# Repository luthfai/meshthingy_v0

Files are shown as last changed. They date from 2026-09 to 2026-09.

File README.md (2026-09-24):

# meshthingy v0

> An off-grid LoRa mesh communicator — a pocket-sized ESP32-S3 node that sends
> text and GPS position over kilometres of open ground, with no cell tower, no
> SIM, no subscription, and no internet.

<sub>KiCad 10 · 2-layer · 71 × 46 mm · ESP32-S3 + SX1262-class LoRa · USB-C · Li-Ion</sub>

<p align="center">
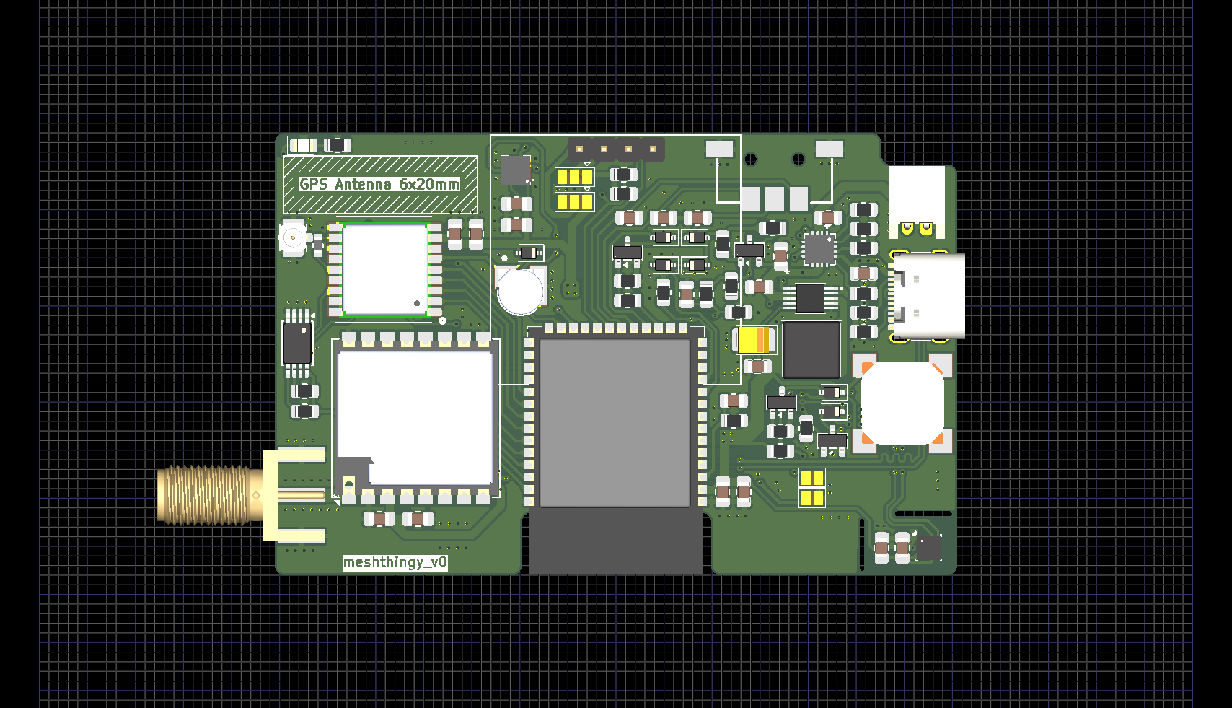
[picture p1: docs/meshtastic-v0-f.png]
meshthingy v0 board, front view
  
</p>

---

## What this board is for

Phones stop working the moment you leave coverage. **meshthingy** doesn't need
coverage — it *is* the network.

Each board is one node in a self-healing [Meshtastic](https://meshtastic.org)
mesh. Nodes talk directly to each other over licence-free LoRa radio, and every
node automatically relays traffic for its neighbours. Two units give you a
private long-range walkie-talkie for text; a handful scattered across a valley,
a campsite, a ridgeline, or a city block give everyone in that area a shared
messaging network that keeps working when nothing else does.

Because LoRa trades bandwidth for range and power, a node runs for **days** on a
small Li-Ion cell and reaches **several kilometres** line-of-sight — far past
Wi-Fi or Bluetooth, and without the power budget a cellular radio demands.

Typical uses: hiking and backcountry trips, sailing, off-road convoys, festival
and event crews, neighbourhood emergency preparedness, and as a low-cost
long-range telemetry link for remote sensors.

The onboard GPS, environmental and motion sensors mean a node is useful even
with nobody holding it — drop one on a hilltop as a solar-powered repeater and
it becomes a weather station that also extends everyone's range.

## Features

- **ESP32-S3-WROOM-1** — dual-core MCU with Wi-Fi and Bluetooth LE for phone pairing
- **HT-RA62 LoRa module** — long-range sub-GHz radio, U.FL *and* SMA edge-mount antenna options
- **ATGM336H GNSS** — position reporting, with a rechargeable backup cell for warm starts
- **0.96" OLED** — read messages without a phone
- **BME280** — temperature, humidity, barometric pressure
- **LIS3DSH accelerometer** — wake-on-motion and orientation, with interrupt to the MCU
- **USB-C charging** — BQ24072 Li-Ion charger with power-path, so it runs while charging
- **JST-PH battery connector** — standard single-cell Li-Ion / LiPo
- **Vibration motor driver** — SI2302 low-side switch with flyback diode, for silent alerts in a pocket
- **Buzzer, status LED, and a side lever switch** for headless operation
- **Test points** on every bus for bring-up and debugging

## System architecture

```mermaid
flowchart TB
    subgraph RF["📡 Radio"]
        LORA["<b>U4 · HT-RA62</b><br/>LoRa transceiver"]
        UFL["J3 · U.FL"]
        SMA["J4 · SMA<br/>edge mount"]
        LORA --- UFL
        LORA --- SMA
    end

    subgraph CORE["🧠 Core"]
        MCU["<b>U7 · ESP32-S3-WROOM-1</b><br/>Wi-Fi · BLE · dual core"]
    end

    subgraph NAV["🛰️ Navigation"]
        GPS["<b>U2 · ATGM336H</b><br/>GNSS receiver"]
        EEP["U8 · AT24C32<br/>almanac EEPROM"]
        BAT2["C13 · XH414H<br/>backup cell"]
        GPS -->|"private I²C"| EEP
        BAT2 -.->|"keeps time"| GPS
    end

    subgraph IO["🔌 I²C peripherals"]
        OLED["U1 · 0.96in OLED"]
        BME["U9 · BME280<br/>temp · humidity · pressure"]
        ACC["U10 · LIS3DSH<br/>accelerometer"]
    end

    subgraph UX["🎛️ Interface"]
        BUZ["LS1 · buzzer"]
        LED["D2 · status LED"]
        SW["U5 · lever switch"]
        VIB["Q4 · SI2302<br/>vibration motor"]
    end

    MCU <==>|"<b>SPI</b> + BUSY/RST/DIO1"| LORA
    MCU <-->|"<b>UART</b> + 1PPS"| GPS
    MCU <-->|"<b>I²C</b> · IO13/IO14"| OLED
    MCU <-->|"<b>I²C</b>"| BME
    MCU <-->|"<b>I²C</b> + INT→IO48"| ACC
    MCU --> BUZ
    MCU --> LED
    MCU -->|IO15| VIB
    SW --> MCU

    classDef core fill:#4f46e5,stroke:#3730a3,color:#fff,stroke-width:2px
    classDef radio fill:#0891b2,stroke:#0e7490,color:#fff
    classDef nav fill:#059669,stroke:#047857,color:#fff
    classDef periph fill:#d97706,stroke:#b45309,color:#fff
    classDef ux fill:#7c3aed,stroke:#6d28d9,color:#fff
    class MCU core
    class LORA,UFL,SMA radio
    class GPS,EEP,BAT2 nav
    class OLED,BME,ACC periph
    class BUZ,LED,SW,VIB ux
```

## Power path

USB-C and the battery both feed a power-path charger, so the node keeps running
while it charges and switches over seamlessly when USB is unplugged.

```mermaid
flowchart LR
    USB["<b>J1</b><br/>USB-C<br/>5 V in"] -->|VBUS| CHG
    BATT["<b>J2</b><br/>Li-Ion cell<br/>JST-PH"] <-->|charge / discharge| CHG
    CHG["<b>U6 · BQ24072</b><br/>Li-Ion charger<br/>+ power path"] -->|VSYS| BUCK
    BUCK["<b>U3 · TPS62046</b><br/>step-down<br/>via L2"] -->|"+3V3"| RAIL

    RAIL["<b>+3V3 rail</b>"] --> M1["ESP32-S3"]
    RAIL --> M2["LoRa"]
    RAIL --> M3["GNSS"]
    RAIL --> M4["Sensors + OLED"]
    RAIL --> M5["Buzzer + vib motor"]

    classDef src fill:#dc2626,stroke:#991b1b,color:#fff,stroke-width:2px
    classDef conv fill:#ea580c,stroke:#c2410c,color:#fff,stroke-width:2px
    classDef rail fill:#16a34a,stroke:#15803d,color:#fff,stroke-width:2px
    classDef load fill:#475569,stroke:#334155,color:#fff
    class USB,BATT src
    class CHG,BUCK conv
    class RAIL rail
    class M1,M2,M3,M4,M5 load
```

## Board

| | |
| --- | --- |
| **Dimensions** | 71.00 × 46.00 mm, 1.0 mm corner radius |
| **Stackup** | 2 layers (F.Cu / B.Cu), 1.6 mm |
| **Components** | 91 footprints, 350 pads (326 SMD, 22 through-hole, 2 NPTH), 373 vias |
| **Density** | 66% front, 9% back — almost everything lives on the front |
| **Copper** | GND pour on both layers, with keepout zones under the antennas |
| **Routing** | Rounded track corners throughout (see `meshtastic-v0.round-tracks-config`) |
| **Design rules** | 0.175 mm clearance, 0.2 mm minimum track, 0.6 / 0.3 mm vias |
| **Assembly** | All SMD, 0805 passives — hand-solderable |

Everything routes on two layers, which keeps this a cheap board to order from any
prototype fab at standard tolerances.

### Assembled views

<table>
  <tr>
    <td width="50%" align="center">
      Front, populated<br>
      <sub><b>Front</b> — LoRa and GNSS modules, ESP32-S3, USB-C, buzzer, GPS backup cell, motor driver</sub>
    </td>
    <td width="50%" align="center">
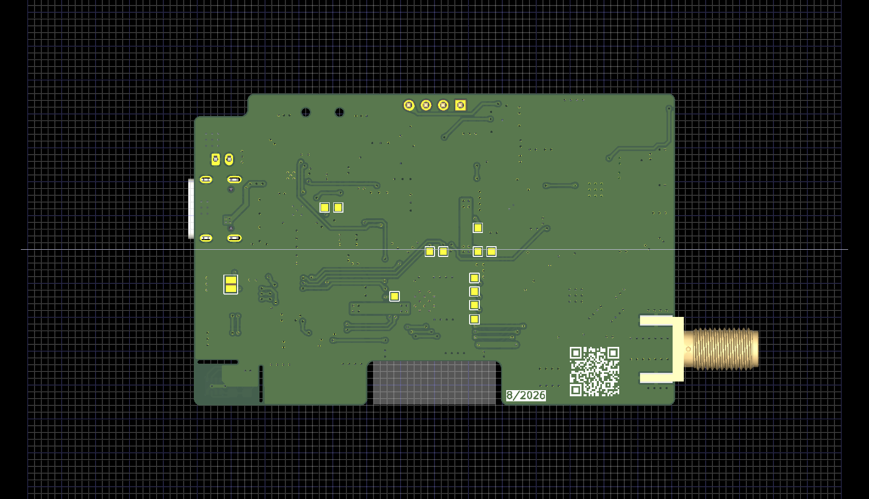
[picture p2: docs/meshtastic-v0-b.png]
Back, populated
      <br>
      <sub><b>Back</b> — labelled test points for every bus, vibration motor pads (<code>JP1</code>), SMA edge launch</sub>
    </td>
  </tr>
</table>

### PCB layer views

Copper, silkscreen and board outline, plotted straight from the layout. The back
view is mirrored so its silkscreen reads the right way round.

<table>
  <tr>
    <td width="50%" align="center">
      Front copper and silkscreen<br>
      <sub><b>F.Cu + F.SilkS</b> — signal routing over the front ground pour; <code>B</code>/<code>R</code> are the boot and reset pads</sub>
    </td>
    <td width="50%" align="center">
      Back copper and silkscreen<br>
      <sub><b>B.Cu + B.SilkS</b> — mirrored; back pour with the test-point field and motor pads</sub>
    </td>
  </tr>
</table>

The RF section is deliberately sparse: the pours are cut back under both antenna
launches, and the GPS patch keepout is marked on the silkscreen so nothing gets
placed under it during assembly.

Regenerate these plots after any layout change:

```bash
kicad-cli pcb export svg --output docs/layers-front.svg \
  --layers "F.Cu,F.SilkS,Edge.Cuts" \
  --page-size-mode 2 --exclude-drawing-sheet --check-zones --mode-single \
  meshtastic-v0.kicad_pcb

kicad-cli pcb export svg --output docs/layers-back.svg \
  --layers "B.Cu,B.SilkS,Edge.Cuts" --mirror \
  --page-size-mode 2 --exclude-drawing-sheet --check-zones --mode-single \
  meshtastic-v0.kicad_pcb
```

## Pin map

| Function | ESP32-S3 pin | Goes to |
| --- | --- | --- |
| LoRa SCK | TXD0 / GPIO43 | `U4` pin 12 |
| LoRa data | IO1, IO2 | `U4` pins 13, 14 |
| LoRa CS | IO6 | `U4` NSS |
| LoRa DIO1 | IO4 | `U4` interrupt |
| LoRa RESET | IO5 | `U4` reset |
| LoRa BUSY | RXD0 / GPIO44 | `U4` pin 10 |
| GPS TX → MCU | IO42 | `U2` TXD |
| GPS RX ← MCU | IO41 | `U2` RXD |
| GPS 1PPS | IO40 | `U2` timing pulse |
| GPS RESET / enable | IO38, IO39 | `U2` |
| I²C SDA / SCL | IO13 / IO14 | OLED, BME280, LIS3DSH |
| Accelerometer INT | IO48 | `U10` INT1 |
| Vibration motor | IO15 | `Q4` gate (10k pull-down `R23`) |
| Buzzer | IO16 | `Q1` gate (10k pull-down `R11`) |
| Status LED | IO21 | `D2` via `R22` |
| Spare / test | IO7, IO47 | back-side test points `IO7`, `IO47` |

## Schematic layout

The design is hierarchical — root sheet [meshtastic-v0.kicad_sch](meshtastic-v0.kicad_sch):

| Sheet | Contents |
| --- | --- |
| [Power Management](Power%20Management.kicad_sch) | BQ24072 charger, TPS62046 buck, load switching |
| [Microcontroller](Microcontroller.kicad_sch) | ESP32-S3-WROOM-1, boot and reset pads |
| [LORA](LORA.kicad_sch) | HT-RA62 module, U.FL and SMA antenna paths |
| [GPS](GPS.kicad_sch) | ATGM336H, AT24C32 EEPROM, backup cell |
| [Display](Display.kicad_sch) | 0.96" OLED and its pinout-select jumpers |
| [Air Sensors](Air%20Sensors.kicad_sch) | BME280 |
| [Accelerometer](Accelerometer.kicad_sch) | LIS3DSH |
| [Peripherals](Peripherals.kicad_sch) | Buzzer and vibration motor drivers, status LED, test points |
| [Connectors](Connectors.kicad_sch) | USB-C receptacle, JST-PH battery |

## Building it

Open [meshtastic-v0.kicad_pro](meshtastic-v0.kicad_pro) in **KiCad 10** or newer.
All custom symbols and footprints live in [libs/](libs/) and are referenced through
`${KIPRJMOD}`, so the project is self-contained — clone and open, nothing else to install.

Generate fabrication files from the command line:

```bash
# Gerbers + drill, ready to zip and upload to a fab
kicad-cli pcb export gerbers --output fab/ meshtastic-v0.kicad_pcb
kicad-cli pcb export drill   --output fab/ meshtastic-v0.kicad_pcb

# Bill of materials and pick-and-place
kicad-cli sch export bom       --output bom.csv meshtastic-v0.kicad_sch
kicad-cli pcb export pos       --output pos.csv meshtastic-v0.kicad_pcb

# 3D render
kicad-cli pcb render --output board.png meshtastic-v0.kicad_pcb
```

Generated outputs are gitignored — regenerate them, or attach them to a release tag.

### Assembly note

`JP3` and `JP4` are three-way solder jumpers that select which OLED pin gets
`+3V3` and which gets `GND`, so the footprint accepts display modules with either
pinout. They ship **unbridged** — bridge them to match the module you source
before expecting the display to light up.

`JP1` on the back is not a jumper. It's the pair of solder pads for the vibration
motor. Solder a coin or pager-style motor's leads across it: the pad on the
`+3V3` side takes the red lead and the pad on the `Q4` drain side takes the black
lead. `D9` clamps the motor's flyback, so the motor runs straight off the
`+3V3` rail.

`B` and `R` on the front are the **BOOT** and **RESET** pads. To put the ESP32-S3
into the ROM bootloader, short `B` while you tap `R`.

## Firmware

The board targets [Meshtastic](https://meshtastic.org) firmware on the ESP32-S3.
Peripheral pin assignments follow the map above; the ESP32-S3 GPIO matrix means
bus pins are remappable in firmware if a variant config needs to differ.

## Repository notes

`.history/` is KiCad 10's Local History — a separate nested git repository of
autosaves. It is gitignored and should stay that way. Delete it freely if you
don't need the local undo history.

---

<sub>Meshtastic® is a registered trademark of Meshtastic LLC. This is an
independent hardware design and is not affiliated with or endorsed by Meshtastic LLC.</sub>

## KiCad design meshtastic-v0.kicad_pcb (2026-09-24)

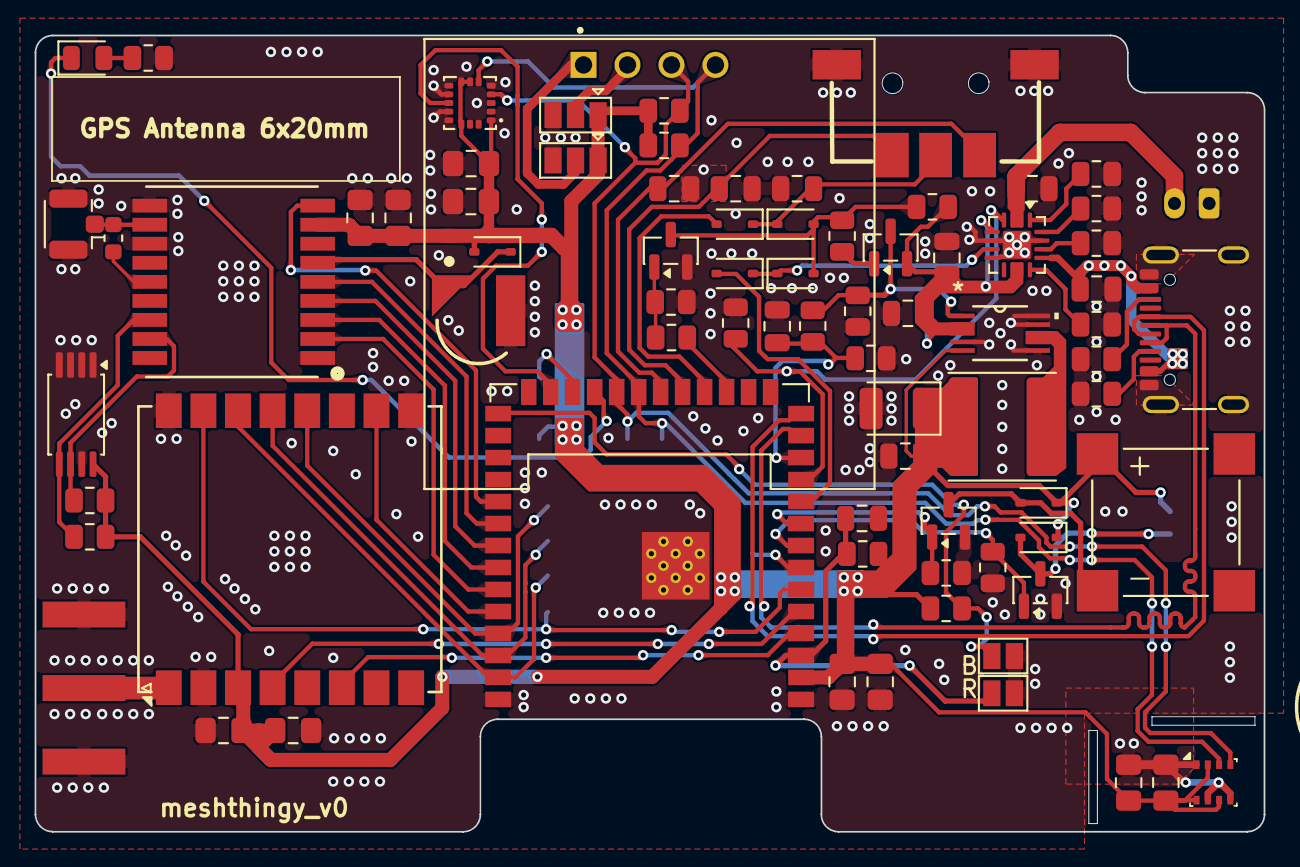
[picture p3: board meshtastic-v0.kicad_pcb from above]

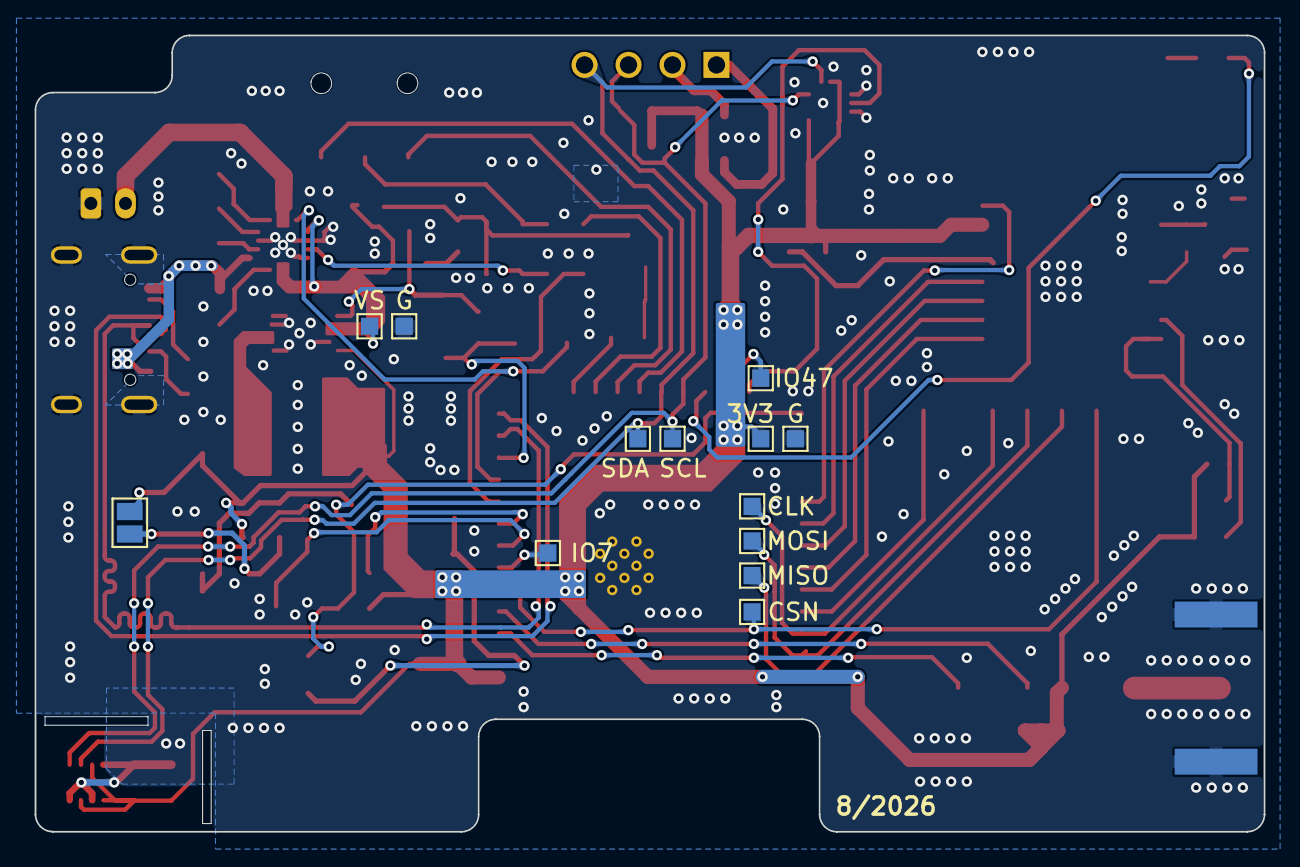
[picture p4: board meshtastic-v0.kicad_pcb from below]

Board: 2 copper layers, 71.0 x 46.0 mm, 91 parts (13 on the bottom side), 60 nets.

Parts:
3V3: 3V3; TestPoint_Pad_1.0x1.0mm
B: Boot; SolderJumper-2_P1.3mm_Open_Pad1.0x1.5mm
C1, C10, C19, C21, C23, C24: 100nF; C_0805_2012Metric_Pad1.18x1.45mm_HandSolder
C2, C9, C18, C20: 10uF; C_0805_2012Metric_Pad1.18x1.45mm_HandSolder
C3, C5: 4u7; C_0805_2012Metric
C4, C6, C17: 1u; C_0805_2012Metric
C7, C8, C11: 100n; C_0805_2012Metric
C12: 22u; C_0805_2012Metric
C13: XH414H-IV01E; CAP_XH414H-IV01E
C14: 10u; C_0805_2012Metric
C16: 22u; CP_EIA-3528-15_AVX-H
CLK: CLK; TestPoint_Pad_1.0x1.0mm
CSN: CSN; TestPoint_Pad_1.0x1.0mm
D1: 1N4148WS; D_SOD-323
D2: LED; LED_0805_2012Metric
D4, D5, D6, D7, D8, D9: 1N5819WS; D_SOD-323
G: GND; TestPoint_Pad_1.0x1.0mm
G#2: GND; TestPoint_Pad_1.0x1.0mm
IO7: IO15; TestPoint_Pad_1.0x1.0mm
IO47: IO47; TestPoint_Pad_1.0x1.0mm
J1: USB_C_Receptacle_USB2.0_16P; USB_C_Receptacle_G-Switch_GT-USB-7010ASV
J2: Conn_01x02_Pin; JST_PH_S2B-PH-K_1x02_P2.00mm_Horizontal
J3: Conn_Coaxial; U.FL_Hirose_U.FL-R-SMT-1_Vertical
J4: Conn_Coaxial; SMA_Amphenol_132289_EdgeMount
JP1: SolderJumper_2_Open; SolderJumper-2_P1.3mm_Open_Pad1.0x1.5mm
JP3, JP4: EN1; SolderJumper-3_P1.3mm_Open_Pad1.0x1.5mm
L1: 47nH; L_0603_1608Metric
L2: 6.8u; L_Changjiang_FNR6045S
LS1: SMT-0927-S-14-R; XDCR_SMT-0927-S-14-R
MISO: MISO; TestPoint_Pad_1.0x1.0mm
MOSI: MOSI; TestPoint_Pad_1.0x1.0mm
Q1, Q4: SI2302; SOT-23
Q2: Q_PNP_BEC; SOT-23
Q3: Q_NPN_BEC; SOT-23
R: Reset; SolderJumper-2_P1.3mm_Open_Pad1.0x1.5mm
R1, R2: 5k1; R_0805_2012Metric
R3, R6, R7, R8, R9, R11, R19, R20, R23: 10k; R_0805_2012Metric
R4, R22: 1k; R_0805_2012Metric
R5: 1k2; R_0805_2012Metric
R10, R12, R13, R21: 4k7; R_0805_2012Metric
R14, R15, R16, R17, R18: 100k; R_0805_2012Metric
SCL: SCL; TestPoint_Pad_1.0x1.0mm
SDA: SDA; TestPoint_Pad_1.0x1.0mm
U1: DM-OLED096-636; MODULE_DM-OLED096-636
U2: ATGM336H; ATGM336H-5N
U3: TPS62046DGQR; DGQ10_1P88X1P57
U4: HT-RA62; Ai-Thinker-Ra-01-LoRa
U5: Lever Switch TMHU26; tmhu26
U6: BQ24072RGT; VQFN-16-1EP_3x3mm_P0.5mm_EP1.6x1.6mm
U7: ESP32-S3-WROOM-1
U8: AT24C32A; TSSOP-8_4.4x3mm_P0.65mm
U9: BME280; Bosch_LGA-8_2.5x2.5mm_P0.65mm_ClockwisePinNumbering
U10: LIS3DSHTR; LGA16R50P5X3_300X300X100N
VS: VS; TestPoint_Pad_1.0x1.0mm

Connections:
+3V3: 3V3.1 (1_1), C1.1, C2.1, C9.1, C10.1, C14.2, C16.1, C18.1, C19.1, C20.1, C21.1, C23.1, C24.1, D1.2 (A), D5.1 (K), D9.1 (K), JP1.2 (B), JP3.1 (A), JP4.1 (A), L2.2, LS1.P, R10.2, R12.1, R13.1, R19.1, R20.1, R21.2, U2.8 (VCC), U3.5 (FB), U4.3 (3V3), U7.2 (3V3), U8.8 (VCC), U9.2 (CSB), U9.6 (VDDIO), U9.8 (VDD), U10.1 (VDD_IO), U10.7 (SDO/SA0), U10.8 (CS), U10.14 (VDD)
/Accelerometer/INT: U7.25 (IO48), U10.11 (INT1)
/Accelerometer/SCL: R10.1, SCL.1 (1_1), U1.3 (SCL), U7.22 (IO14), U9.4 (SCK), U10.4 (SCL/SPC)
/Accelerometer/SDA: R12.2, SDA.1 (1_1), U1.4 (SDA), U7.21 (IO13), U9.3 (SDI), U10.6 (SDA/SDI/SDO)
/Connectors/D+: J1.A6 (D+), J1.B6 (D+), U7.14 (USB_D+)
/Connectors/D-: J1.A7 (D-), J1.B7 (D-), U7.13 (USB_D-)
/Connectors/VBATT: C5.1, J2.2, U6.2 (BAT), U6.3 (BAT)
/Connectors/VBUS: C4.2, J1.A4 (VBUS), J1.A9 (VBUS), J1.B4 (VBUS), J1.B9 (VBUS), U6.13 (IN)
/GPS/GPS_EN: U2.5 (ON/OFF), U7.32 (IO39)
/GPS/GPS_PPS: U2.4 (1PPS), U7.33 (IO40)
/GPS/GPS_RST: U2.9 (nRESET), U7.31 (IO38)
/GPS/GPS_RX: U2.3 (RXD), U7.34 (IO41)
/GPS/GPS_SCL: R21.1, U2.17 (SCL), U8.6 (SCL)
/GPS/GPS_SDA: R13.2, U2.16 (SDA), U8.5 (SDA)
/GPS/GPS_TX: U2.2 (TXD), U7.35 (IO42)
/GPS/GPS_VBATT: C13.1, D1.1 (K), U2.6 (VBAT)
/LORA/LORA_BUSY: U4.10 (BUSY), U7.36 (RXD0)
/LORA/LORA_INT: U4.6 (DIO1), U7.4 (IO4)
/LORA/LORA_RST: U4.4 (~RESET), U7.5 (IO5)
/LORA/SPI2_CLK: CLK.1 (1_1), U4.12 (SCK), U7.37 (TXD0)
/LORA/SPI2_CS_N: CSN.1 (1_1), U4.15 (~NSS), U7.6 (IO6)
/LORA/SPI2_MISO: MISO.1 (1_1), U4.14 (MOSI), U7.39 (IO1)
/LORA/SPI2_MOSI: MOSI.1 (1_1), U4.13 (MISO), U7.38 (IO2)
/Microcontroller/BAT_ADC: C6.1, R16.1, R17.2, U7.12 (IO8)
/Microcontroller/BOOT: B.2 (B), R20.2, U7.27 (IO0)
/Microcontroller/BUZZER: Q1.1 (G), R11.2, U7.9 (IO16)
/Microcontroller/CHG_EN: R7.1, U6.4 (~CE), U7.11 (IO18)
/Microcontroller/IO07: IO7.1 (1_1), U7.7 (IO7)
/Microcontroller/IO47: IO47.1 (1_1), U7.24 (IO47)
/Microcontroller/PUSH_CCW: C7.1, U5.2, U7.19 (IO11)
/Microcontroller/PUSH_CW: C11.1, U5.1, U7.20 (IO12)
/Microcontroller/PUSH_DWN_MCU: D7.2 (A), U7.18 (IO10)
/Microcontroller/P_GOOD: D4.2 (A), U7.10 (IO17)
/Microcontroller/RESET: C17.2, R.2 (B), R19.2, U7.3 (EN)
/Microcontroller/STATUS_LED: D2.1 (K), U7.23 (IO21)
/Microcontroller/SYS_EN: R9.1, U7.17 (IO9)
/Microcontroller/VIB_MTR: Q4.1 (G), R23.2, U7.8 (IO15)
/Power Management/BUCK_EN: Q2.3 (C), R15.2, R16.2, U3.1 (EN)
/Power Management/PGOOD: D4.1 (K), D6.1 (K), U6.7 (~PGOOD)
/Power Management/PUSH_DWN: C8.1, D7.1 (K), D8.1 (K), U5.4
GND: B.1 (A), C1.2, C2.2, C3.2, C4.1, C5.2, C6.2, C7.2, C8.2, C9.2, C10.2, C11.2, C12.2, C13.2, C14.1, C16.2, C17.1, C18.2, C19.2, C20.2, C21.2, C23.2, C24.2, G.1 (1_1), G#2.1 (1_1), J1.A1 (GND), J1.A12 (GND), J1.B1 (GND), J1.B12 (GND), J1.SH (SHIELD), J2.1, J3.2 (Ext), J4.2 (Ext), JP3.3 (B), JP4.3 (B), Q1.2 (S), Q3.2 (E), Q4.2 (S), R.1 (A), R1.2, R2.2, R3.2, R4.2, R5.2, R6.2, R7.2, R11.1, R15.1, R17.1, R18.1, R22.1, R23.1, U2.1 (GND), U2.10 (GND), U2.12 (GND), U3.4 (GND), U3.6 (MODE), U3.9 (PGND), U3.10 (PGND), U4.2 (GND), U4.9 (GND), U4.16 (GND), U5.3, U5.5, U6.6 (EN1), U6.8 (VSS), U6.15 (TD), U6.17 (VSS), U7.1 (GND), U7.40 (GND), U7.41 (GND), U8.1 (A0), U8.2 (A1), U8.3 (A2), U8.4 (GND), U8.7 (WP), U9.1 (GND), U9.5 (SDO), U9.7 (GND), U10.5 (GND), U10.10 (RES), U10.12 (GND)
unnamed: D2.2 (A), R22.2
unnamed: D5.2 (A), LS1.N, Q1.3 (D)
unnamed: D6.2 (A), D8.2 (A), Q3.3 (C), R8.1, R14.1
unnamed: D9.2 (A), JP1.1 (A), Q4.3 (D)
unnamed: J1.A5 (CC1), R2.1
unnamed: J1.B5 (CC2), R1.1
unnamed: J3.1 (In), L1.1, U2.11 (RF_IN)
unnamed: J4.1 (In), U4.1 (ANT)
unnamed: JP3.2 (C), U1.2 (VCC_IN)
unnamed: JP4.2 (C), U1.1 (GND)
unnamed: L2.1, U3.7 (SW), U3.8 (SW)
unnamed: Q2.1 (B), R8.2
unnamed: Q3.1 (B), R9.2, R18.2
unnamed: L1.2, U2.14 (VCC_RF)
unnamed: R5.1, U6.12 (ILIM)
unnamed: R4.1, U6.16 (ISET)
unnamed: R6.1, U6.14 (TMR)
unnamed: R3.1, U6.1 (TS)
VSYS: C3.1, C12.1, Q2.2 (E), R14.2, U3.2 (VIN), U3.3 (VIN), U6.5 (EN2), U6.10 (OUT), U6.11 (OUT), VS.1 (1_1)

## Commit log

2026-08-10 meshthingy_v0 init
    [Accelerometer.kicad_sch, Air Sensors.kicad_sch, Connectors.kicad_sch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]
2026-08-10 Add project README, fix git hygiene
    - Ignore .history/ (KiCad Local History is a nested 77 MB git repo;
    committing it would create a broken gitlink)
    - Untrack meshtastic-v0.kicad_prl (local editor UI state)
    - Ignore generated gerber/drill/BOM fabrication outputs
    - Replace the stray KiCad local-history README.txt with a real
    project README covering the board, blocks, and ERC/DRC status
2026-08-10 Clean up project library tables
    - Remove 5 sym-lib-table and 5 fp-lib-table entries pointing at libs/
    directories that no longer exist (TLV75733PDBVR, ESP32-C3-MINI-1-N4,
    NEO_7M_0, AHT10, PRESSURE-BMP180_LGA7_); all verified unreferenced
    by any schematic or the PCB
    - Register libs/RA-01SH/ as symbol library 'RAa01SH' so U4's
    Ai-Thinker-Ra-01SH symbol is library-managed rather than surviving
    only via the schematic's embedded cache
    - Delete Sensors.kicad_sch, an empty sheet not referenced by the root
    - Note in README that the merged +3V3 rail labels are intentional
    ERC warnings 15 -> 14; all library table paths now resolve.
    [Sensors.kicad_sch]
2026-08-10 Connect VSYS/3V3 sheet pins, sync R22, document remaining ERC state
    Schematic/PCB edits: wire up the dangling VSYS and 3V3 hierarchical
    sheet pins on the root sheet, and re-sync the board so R22 reads 1k
    on both sides.
    ERC 8 -> 6 errors; schematic parity 3 -> 2 issues; DRC still 0
    violations and 0 unconnected pads.
    README: explain each of the 6 remaining ERC errors (all PWR_FLAG /
    no-connect annotations or the intentional JP3/JP4 jumper routing,
    none of them wiring defects), and add an assembly note that JP3/JP4
    ship unbridged and must be bridged for the display to receive power.
    [meshtastic-v0.kicad_pcb, meshtastic-v0.kicad_sch]
2026-08-10 Round board corners, re-annotate test points, rewrite README for GitHub
    Board: 1.0 mm radius corners; outline now 71.00 x 46.00 mm.
    Schematic: test points re-annotated to signal names (SDA1, SLC1,
    CSN1, CLK1, MOSI1, MISO1, VS1, G1, G2, IO7, IO15, IO47, RST1, BOOT1).
    README rewritten as a GitHub landing page: explains what the board is
    for, adds Mermaid system-architecture and power-path diagrams, a
    verified pin map traced from the netlist, board specs, and fab
    instructions. Drops the ERC/DRC status and issue-tracking sections.
    [GPS.kicad_sch, LORA.kicad_sch, Microcontroller.kicad_sch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]
2026-08-10 Add 3D renders and PCB layer views to README
    - docs/meshtastic-v0-{f,b}.png: 3D renders of the populated board
    - docs/layers-{front,back}.svg: F.Cu/B.Cu + silkscreen + outline plots
    exported with kicad-cli, back mirrored so silk reads correctly, on a
    dark canvas so they render in both GitHub themes
    - README: hero render, side-by-side assembled and layer view galleries,
    and the kicad-cli commands to regenerate the plots
    - Refresh board stats from kicad-cli pcb export stats: 90 footprints,
    342 pads (318 SMD / 22 TH), 71.0000 x 46.0000 mm
    [meshtastic-v0.kicad_pcb]
2026-09-24 fixed ground clearance, and tidy up
    [meshtastic-v0-rounded.kicad_pcb]
2026-09-24 vib motor
    [Microcontroller.kicad_sch, Peripherals.kicad_sch, meshtastic-v0.kicad_pcb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]
2026-09-24 added vib motor fix
    [Microcontroller.kicad_sch, Peripherals.kicad_sch, meshtastic-v0.kicad_pcb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]
2026-09-24 pcb render update
    [meshtastic-v0.kicad_pcb]
